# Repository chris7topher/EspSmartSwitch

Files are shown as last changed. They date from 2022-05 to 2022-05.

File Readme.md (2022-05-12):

# DIY ESP8266 SmartSwitch

## Folder structure
### 3D-Parts
Here you can find the 3D models for the 3D printed parts

### Arduino
If you want to use your own code with MQTT instead of Tasmota you can find an example for Arduino here

### PCB
Here you find the schematic, the Gerber data and the PCB design

### Tasmota
Here you can find the tasmota configuration and a ready built tasmota firmware for the SmartSwitch

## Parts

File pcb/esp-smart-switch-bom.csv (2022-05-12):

ID | Name | Designator | Footprint | Quantity | Manufacturer Part | Manufacturer | Supplier | Supplier Part | Price | Pins | 3DModel | Assembly Type | LCSC Assembly | Paste Type | Contributor | Package Display | SMT Type | description | link
1 | R120 | R1 | R0603 | 1 | RNCS0603BTC10R0 | SEI(Stackpole Electronics Inc.) | LCSC | C2523745 | 0.093 | 2 | R0603_L1.6-W0.8-H0.8 |  |  |  | LCSC |  |  |  | https://item.szlcsc.com/137208.html
2 | RGB LED | LED | LED_WP154A4SEJ3VBDZGC/CA_KNB | 1 | WP154A4SEJ3VBDZGC/CA | Kingbright | Mouser | 604-WP154A43VBDZGCCA |  | 4 | LED-TH-5mm_B |  |  |  | Chamberland | No |  |  | https://www.mouser.com/ProductDetail/Kingbright/WP154A4SEJ3VBDZGC-CA
3 | SKHHCRA010 | SW1,SW2,SW3,SW4 | SW-TH_4P-L6.0-W6.0-P4.50-LS6.5 | 4 | SKHHCRA010 | ALPS Electric | LCSC | C139810 | 0.226 | 4 | SW-TH_4P-L6.0-W6.0-H5.0-LS6.5-P4.50 | manualWeld | Yes | expand | LCSC |  | Extend |  | https://item.szlcsc.com/14483.html
4 | TTP223E-BA6 | U1 | SOT-23-6_6PIN-L3.00-W3.00-PITCH0.95-BL | 1 | TTP223E-BA6 | TONTEK | LCSC | C129457 |  | 6 |  |  |  |  |  |  |  |  | https://so.szlcsc.com/global.html?c=&k=C370887
5 | 1uF | C1 | C0805 | 1 | 0805F105M500 | Huaxin S&T | LCSC | C152857 | 0.021 | 2 | C0805_L2.0-W1.3-H1.3 |  |  |  | LCSC |  |  |  | https://item.szlcsc.com/373011.html
6 | 30pF | C2 | C0805 | 1 | 0805F105M500 | Huaxin S&T | LCSC | C152857 | 0.021 | 2 | C0805_L2.0-W1.3-H1.3 |  |  |  | LCSC |  |  |  | https://item.szlcsc.com/373011.html
7 | Header-Male-2.54_1x1 | TOUCH | HDR-TH_1P-P2.54-V-M | 1 | Header-Male-2.54_1x1 | ReliaPro | LCSC | C81276 | 0.007 | 1 | HDR2.54-M-LI-1X1P | manualWeld | Yes | expand | 立创EDA官方封装库 |  | Extend |  | https://item.szlcsc.com/82426.html
8 | 220S-1*4P H=8.5MM Ytype Gold-plated | TEMP | HDR-TH_4P-P2.54-V | 1 | 220S-1*4P H=8.5MM Ytype Gold-plated | Ckmtw | LCSC | C124413 | 0.1 | 4 | HDR-M-2.54_1x4 | manualWeld | Yes | expand | LCSC |  | Extend |  | https://lcsc.com/product-detail/Pin-Header-Female-Header_Made-in-China-Made-in-China-Headers-Pins1-4-pitch2-54mm_C59481.html
9 | ESP-12F(ESP8266MOD) | U2 | WIFIM-SMD_ESP-12F-ESP8266MOD | 1 | ESP-12F(ESP8266MOD) | Ai-Thinker | LCSC | C82891 | 1.731 | 22 | WIFIM-SMD_WIFI-L24.0-W16.0-H3.1 | smtWeld |  | recommend | 立创EDA官方封装库 |  |  |  | https://item.szlcsc.com/84052.html
10 | B | DC_IN | C0402 | 1 |  |  |  |  |  | 2 |  |  |  |  | SparkFun
11 | HLK-PM03 | U6 | TORBEN-PSU | 1 | HLK-PM03 |  |  |  |  | 4 | PWRM-TH_HLK-PM03 |  |  |  | t_andersen
12 | KF350-3.5-2P | U5,U4 | CONN-TH_P3.50_KF350-3.5-2P | 2 | KF350-3.5-2P | Cixi Kefa Elec | LCSC | C474892 | 0.094 | 2 | CONN-TH_P3.50_KF350-3.5-2P | manualWeld | Yes | expand | LCSC |  | Extend |  | https://item.szlcsc.com/481510.html
13 | HT7333-A_C73726 | U7 | TO-92-3_L5.1-W4.1-P1.27-L | 1 | HT7333-A | Holtek Semicon | LCSC | C73726 | 0.173 | 3 | TO-92-3_L4.9-W3.7-P1.27-L |  |  |  | LCSC |  |  |  | https://item.szlcsc.com/39513.html

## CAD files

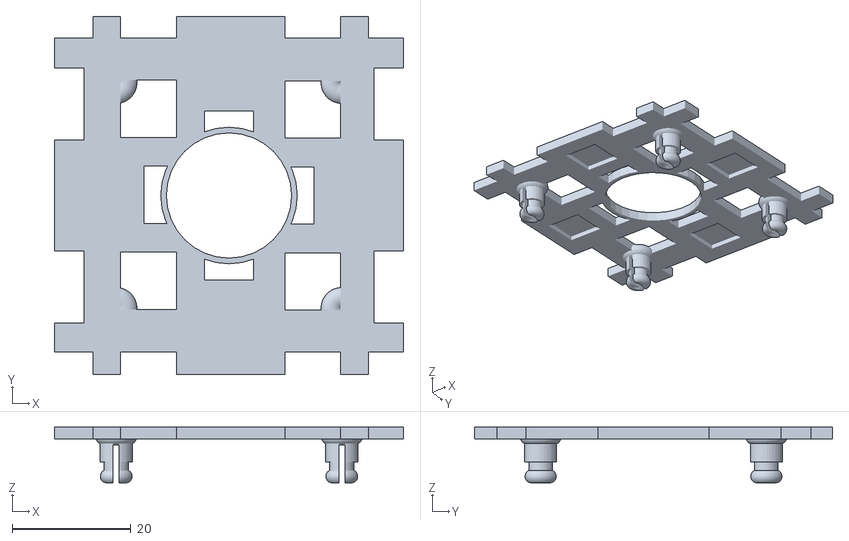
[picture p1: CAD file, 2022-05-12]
3d-parts/glass-holder.stl
58.8 x 60.3 x 9.37

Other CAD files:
3d-parts/glass-holder.blend

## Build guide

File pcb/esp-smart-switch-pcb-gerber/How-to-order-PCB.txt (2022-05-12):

How to Order PCB

Please refer to:
https://docs.easyeda.com/en/PCB/Order-PCB

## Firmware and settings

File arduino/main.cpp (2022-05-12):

#include <Arduino.h>
#include <ESP8266WiFi.h>
#include <ESP8266HTTPClient.h>
#define GET_CHIPID() (ESP.getChipId())

#include <FS.h>
#include <ArduinoOTA.h>
#include <PubSubClient.h>
#include <AutoConnect.h>
#include <SmartButton.h>

#include <AHT10.h>
#include <Wire.h>

uint8_t readStatus = 0;

AHT10 myAHT10(AHT10_ADDRESS_0X38);

#define RGB_RED (1)   // R
#define RGB_GREEN (3) // G
#define RGB_BLUE (0)  // B
int ledState_red = 0;
int ledState_green = 0;
int ledState_blue = 0;

#define BTN_L (13)
#define BTN_T (16)
#define BTN_R (14)
#define BTN_B (12)
#define BTN_C (2)

SmartButton buttons[] = {
  SmartButton("button-left", BTN_L),
  SmartButton("button-top", BTN_T),
  SmartButton("button-center", BTN_C),
  SmartButton("button-right", BTN_R),
  SmartButton("button-bottom", BTN_B)
};

const int SHORT_PRESS_TIME = 500; // 500 milliseconds

#define PARAM_FILE "/param.json"
#define AUX_SETTING_URI "/mqtt_setting"
#define AUX_SAVE_URI "/mqtt_save"
#define AUX_TEST_URI "/test"

typedef ESP8266WebServer WiFiWebServer;
AutoConnect portal;
AutoConnectConfig config;
WiFiClient wifiClient;
PubSubClient mqttClient(wifiClient);

//Definition of functions:
void callback(String topic, byte *message, int length);
void redirect(String uri);
void handleButton(SmartButton *button, byte normalState, int shortPressTime);

//MQTT Settings
String mqttServer = "192.168.178.99";
String mqttPort = "1884";
String mqttUser = "admin";
String mqttPW = "admin";
String mqttDeviceName = "SmartLightSwitch-" + String(GET_CHIPID(), HEX);

// Declare AutoConnectElements for the page asf /mqtt_setting
ACStyle(style, "label+input,label+select{position:sticky;left:120px;width:230px!important;box-sizing:border-box;}");
ACText(header, "<h2>MQTT Settings</h2>", "text-align:center;color:#2f4f4f;padding:10px;");
ACInput(inMqttserver, mqttServer.c_str(), "MQTT-Server", "", "e.g. 192.168.172.99");
ACInput(inMqttport, mqttPort.c_str(), "MQTT Port", "", "e.g. 1883 or 1884");
ACInput(inMqttuser, mqttUser.c_str(), "MQTT User", "", "default: admin");
ACInput(inMqttpw, mqttPW.c_str(), "MQTT Password", "", "default: admin");
ACInput(inMqttDeviceName, mqttDeviceName.c_str(), "MQTT Device Name", "", (String("default: ") + mqttDeviceName).c_str());
ACText(mqttState, "MQTT-State: none", "");
ACSubmit(save, "Save", AUX_SAVE_URI);
ACSubmit(discard, "Discard", "/");
ACElement(newline, "<hr>");
// Declare the custom Web page as /mqtt_setting and contains the AutoConnectElements
AutoConnectAux mqtt_setting(AUX_SETTING_URI, "MQTT Settings", true, {style, header, newline, inMqttserver, inMqttport, newline, inMqttuser, inMqttpw, inMqttDeviceName, newline, mqttState, newline, save, discard});

// Declare AutoConnectElements for the page as /mqtt_save
ACText(caption2, "<h4>Parameters available as:</h4>", "text-align:center;color:#2f4f4f;padding:10px;");
ACText(parameters);
ACSubmit(back2config, "Back", AUX_SETTING_URI);
// Declare the custom Web page as /mqtt_save and contains the AutoConnectElements
AutoConnectAux mqtt_save(AUX_SAVE_URI, "MQTT Settings", false, {caption2, parameters, back2config});

bool mqttConnect()
{
  if (mqttServer.length() <= 0)
  {
    return false;
  }

  mqttClient.setServer(mqttServer.c_str(), atoi(mqttPort.c_str()));
  mqttClient.setCallback(callback);

  if (mqttClient.connect(mqttDeviceName.c_str(), mqttUser.c_str(), mqttPW.c_str()))
  {
    mqttClient.publish((mqttDeviceName + "/ip").c_str(), WiFi.localIP().toString().c_str());
    mqttClient.subscribe((mqttDeviceName + "/led-red").c_str());
    mqttClient.subscribe((mqttDeviceName + "/led-green").c_str());
    mqttClient.subscribe((mqttDeviceName + "/led-blue").c_str());
    mqttState.value = "MQTT-State: <b style=\"color: green;\">Connected</b>";
    return true;
  }
  else
  {
    mqttState.value = "MQTT-State: <b style=\"color: red;\">Disconnected</b>";
  }
  return false;
}

// This functions is executed when some device publishes a message to a topic that your ESP8266 is subscribed to
// Change the function below to add logic to your program, so when a device publishes a message to a topic that
// your ESP8266 is subscribed you can actually do something
void callback(String topic, byte *message, int length)
{

  String messageTemp;
  for (int i = 0; i < length; i++)
  {
    messageTemp += (char)message[i];
  }
  messageTemp += '\n';

  if (topic == (mqttDeviceName + "/led-red").c_str())
  {
    ledState_red = messageTemp.toInt();
  }
  else if (topic == (mqttDeviceName + "/led-green").c_str())
  {
    ledState_green = messageTemp.toInt();
  }
  else if (topic == (mqttDeviceName + "/led-blue").c_str())
  {
    ledState_blue = messageTemp.toInt();
  }
}

String loadParams()
{
  File param = SPIFFS.open(PARAM_FILE, "r");
  if (param)
  {
    if (mqtt_setting.loadElement(param))
    {
      mqttServer = mqtt_setting["inMqttserver"].value;
      mqttServer.trim();
      mqttPort = mqtt_setting["inMqttport"].value;
      mqttPort.trim();
      mqttUser = mqtt_setting["inMqttuser"].value;
      mqttUser.trim();
      mqttPW = mqtt_setting["inMqttpw"].value;
      mqttPW.trim();
      mqttDeviceName = mqtt_setting["inMqttDeviceName"].value;
      mqttDeviceName.trim();
    }
    param.close();
  }
  return String("");
}

// Retreive the value of each element entered by '/mqtt_setting'.
String saveParams(AutoConnectAux &aux, PageArgument &args)
{
  mqttServer = inMqttserver.value;
  mqttServer.trim();

  mqttPort = inMqttport.value;
  mqttPort.trim();

  mqttUser = inMqttuser.value;
  mqttUser.trim();

  mqttPW = inMqttpw.value;
  mqttPW.trim();

  mqttDeviceName = inMqttDeviceName.value;
  mqttDeviceName.trim();

  // The entered value is owned by AutoConnectAux of /mqtt_setting.
  // To retrieve the elements of /mqtt_setting, it is necessary to get
  // the AutoConnectAux object of /mqtt_setting.
  File param = SPIFFS.open(PARAM_FILE, "w");
  mqtt_setting.saveElement(param, {"inMqttserver", "inMqttport", "inMqttuser", "inMqttpw", "inMqttDeviceName"});
  param.close();

  // Echo back saved parameters to AutoConnectAux page.
  String echo = "Server: " + mqttServer + "<br>";
  echo += "Port: " + mqttPort + "<br>";
  echo += "User: " + mqttUser + "<br>";
  echo += "Password: " + mqttPW + "<br>";
  parameters.value = echo;
  mqttClient.disconnect();
  return String("");
}

void handleRoot()
{
  redirect("/_ac");
}

void redirect(String uri)
{
  WiFiWebServer &webServer = portal.host();
  webServer.sendHeader("Location", String("http://") + webServer.client().localIP().toString() + uri);
  webServer.send(302, "text/plain", "");
  webServer.client().flush();
  webServer.client().stop();
}

void setup()
{
  Wire.begin(SDA, SCL);

  SPIFFS.begin();
  config.title = "MQTT Smart Light Switch";
  config.apid = "esp-smart-light-switch";
  config.autoReconnect = true;
  config.reconnectInterval = 4;   // Seek interval time is 120[s].
  config.psk = "";
  config.autoReset = true;
  config.portalTimeout = 60000; // It will time out in 60 seconds
  config.retainPortal = true;
  portal.config(config);
  loadParams();
  // Join the custom Web pages and register /mqtt_save handler
  portal.join({mqtt_setting, mqtt_save});
  portal.on(AUX_SAVE_URI, saveParams);

  if (portal.begin())
  {
    ArduinoOTA.begin();
  }
  WiFiWebServer &webServer = portal.host();
  webServer.on("/", handleRoot);

  //Handle LEDs
  pinMode(RGB_RED, OUTPUT);
  pinMode(RGB_GREEN, OUTPUT);
  pinMode(RGB_BLUE, OUTPUT);
  analogWrite(RGB_RED, ledState_red);
  analogWrite(RGB_GREEN, ledState_green);
  analogWrite(RGB_BLUE, ledState_blue);

  //Init Buttons
  pinMode(BTN_L, INPUT_PULLUP);
  pinMode(BTN_T, INPUT_PULLDOWN_16);
  pinMode(BTN_C, INPUT_PULLUP);
  pinMode(BTN_R, INPUT_PULLUP);
  pinMode(BTN_B, INPUT_PULLUP);

  myAHT10.begin();
}

void loop()
{
  if (WiFi.status() == WL_CONNECTED)
  {
    //The following things can only be handled if wifi is connected
    ArduinoOTA.handle();
    if (!mqttClient.connected())
    {
      mqttConnect();
    }
    else
    {
      mqttClient.loop();
    }
  }

  // set the LED with the ledState of the variable:
  analogWrite(RGB_RED, ledState_red);
  analogWrite(RGB_GREEN, ledState_green);
  analogWrite(RGB_BLUE, ledState_blue);

  //BTN
  handleButton(&buttons[0], HIGH, SHORT_PRESS_TIME);
  handleButton(&buttons[1], LOW, SHORT_PRESS_TIME);
  handleButton(&buttons[2], HIGH, SHORT_PRESS_TIME * 2);
  handleButton(&buttons[3], HIGH, SHORT_PRESS_TIME);
  handleButton(&buttons[4], HIGH, SHORT_PRESS_TIME);

  //*Temperature
  if(millis() % 5000 == 0){
    mqttClient.publish((mqttDeviceName + "/temperature").c_str(), String(myAHT10.readTemperature()).c_str());
    mqttClient.publish((mqttDeviceName + "/humidity").c_str(), String(myAHT10.readHumidity()).c_str());
  }
  portal.handleClient();
}

void handleButton(SmartButton *btn, byte normalState, int shortPressTime)
{
  int currentState = digitalRead(btn->pin);

  if (btn->lastState == normalState && currentState != normalState)
  { // button is pressed
    btn->pressedTime = millis();
    btn->isPressing = true;
    btn->isLongDetected = false;
  }
  else if (btn->lastState != normalState && currentState == normalState)
  { // button is released
    btn->isPressing = false;
    btn->releasedTime = millis();

    long pressDuration = btn->releasedTime - btn->pressedTime;

    if (pressDuration < shortPressTime && pressDuration > 20)
      mqttClient.publish((mqttDeviceName + "/" + btn->name).c_str(), "S");
  }

  if (btn->isPressing == true && btn->isLongDetected == false)
  {
    long pressDuration = millis() - btn->pressedTime;

    if (pressDuration > shortPressTime)
    {
      mqttClient.publish((mqttDeviceName + "/" + btn->name).c_str(), "L");
      btn->isLongDetected = true;
    }
  }
  // save the the last state
  btn->lastState = currentState;
}

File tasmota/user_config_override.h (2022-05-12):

/*
  user_config_override.h - user configuration overrides my_user_config.h for Tasmota

  Copyright (C) 2021  Theo Arends

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
  You should have received a copy of the GNU General Public License
  along with this program.  If not, see <http://www.gnu.org/licenses/>.
*/

#ifndef _USER_CONFIG_OVERRIDE_H_
#define _USER_CONFIG_OVERRIDE_H_

/*****************************************************************************************************\
 * USAGE:
 *   To modify the stock configuration without changing the my_user_config.h file:
 *   (1) copy this file to "user_config_override.h" (It will be ignored by Git)
 *   (2) define your own settings below
 *
 ******************************************************************************************************
 * ATTENTION:
 *   - Changes to SECTION1 PARAMETER defines will only override flash settings if you change define CFG_HOLDER.
 *   - Expect compiler warnings when no ifdef/undef/endif sequence is used.
 *   - You still need to update my_user_config.h for major define USE_MQTT_TLS.
 *   - All parameters can be persistent changed online using commands via MQTT, WebConsole or Serial.
\*****************************************************************************************************/

/*
Examples :

// -- Master parameter control --------------------
#undef  CFG_HOLDER
#define CFG_HOLDER        4617                   // [Reset 1] Change this value to load SECTION1 configuration parameters to flash

// -- Setup your own Wifi settings  ---------------
#undef  STA_SSID1
#define STA_SSID1         "YourSSID"             // [Ssid1] Wifi SSID

#undef  STA_PASS1
#define STA_PASS1         "YourWifiPassword"     // [Password1] Wifi password
*/
// -- Setup your own MQTT settings  ---------------
#undef  MQTT_HOST
#define MQTT_HOST         "192.168.178.99" // [MqttHost]

#undef  MQTT_PORT
#define MQTT_PORT         1883                   // [MqttPort] MQTT port (10123 on CloudMQTT)

#undef  MQTT_USER
#define MQTT_USER         "enter_your_your_user_here"         // [MqttUser] Optional user

#undef  MQTT_PASS
#define MQTT_PASS         "enter_your_password_here"         // [MqttPassword] Optional password

/*
// You might even pass some parameters from the command line ----------------------------
// Ie:  export PLATFORMIO_BUILD_FLAGS='-DUSE_CONFIG_OVERRIDE -DMY_IP="192.168.1.99" -DMY_GW="192.168.1.1" -DMY_DNS="192.168.1.1"'

#ifdef MY_IP
#undef  WIFI_IP_ADDRESS
#define WIFI_IP_ADDRESS     MY_IP                // Set to 0.0.0.0 for using DHCP or enter a static IP address
#endif

#ifdef MY_GW
#undef  WIFI_GATEWAY
#define WIFI_GATEWAY        MY_GW                // if not using DHCP set Gateway IP address
#endif

#ifdef MY_DNS
#undef  WIFI_DNS
#define WIFI_DNS            MY_DNS               // If not using DHCP set DNS IP address (might be equal to WIFI_GATEWAY)
#endif

#ifdef MY_DNS2
#undef  WIFI_DNS2
#define WIFI_DNS2           MY_DNS2              // If not using DHCP set DNS IP address (might be equal to WIFI_GATEWAY)
#endif

// !!! Remember that your changes GOES AT THE BOTTOM OF THIS FILE right before the last #endif !!!
*/

// Passwords
#undef STA_SSID1
#define STA_SSID1      "YOUR_SSID"

#undef STA_PASS1
#define STA_PASS1      "YOUR_WIFI_PASSWORD"


// Temperatur Sensor
#define USE_AHT1x

// Template
#define USER_TEMPLATE "{\"NAME\":\"SmartSwitch\",\"GPIO\":[418,416,36,417,640,608,1,1,34,35,33,1,96,1],\"FLAG\":0,\"BASE\":18}"

#define USE_WEBSEND_RESPONSE

//HAAS
#undef HOME_ASSISTANT_DISCOVERY_ENABLE
#define HOME_ASSISTANT_DISCOVERY_ENABLE   false

// Use only singe press for fast response, if hold is needed this must be set to false (setoption13)
#undef KEY_ONLY_SINGLE_PRESS  false
#define KEY_ONLY_SINGLE_PRESS   true

#undef FALLBACK_MODULE
#define FALLBACK_MODULE        USER_MODULE

#undef FRIENDLY_NAME
#define FRIENDLY_NAME          "SmartSwitch" 

#undef KEY_HOLD_TIME
#define KEY_HOLD_TIME 10

#undef MQTT_BUTTON_TOPIC
#define MQTT_BUTTON_TOPIC      "1"  

#undef MQTT_CLIENT_ID
#define MQTT_CLIENT_ID "SmartSwitch_%06X"

// Try to disable firmware reset
#undef KEY_DISABLE_MULTIPRESS
#define KEY_DISABLE_MULTIPRESS true

// Disable other temp sensors
#ifdef USE_ADE7953
#undef USE_ADE7953                              
#endif 

#undef MQTT_BUTTONS                              
#define MQTT_BUTTONS true

#ifdef MQTT_SWITCHES
#undef MQTT_SWITCHES                              
#define MQTT_SWITCHES true
#endif 

#ifdef USE_VEML6075
#undef USE_VEML6075                              
#endif 

#undef NTP_SERVER1    
#define NTP_SERVER1 "192.168.178.99"                          

#undef NTP_SERVER2      
#define NTP_SERVER2 ""                        

#undef NTP_SERVER3      
#define NTP_SERVER3 ""                        

#ifdef USE_DOMOTICZ
#undef USE_DOMOTICZ                              
#endif 

#ifdef USE_HOME_ASSISTANT
#undef USE_HOME_ASSISTANT                              
#endif 

#endif  // _USER_CONFIG_OVERRIDE_H_

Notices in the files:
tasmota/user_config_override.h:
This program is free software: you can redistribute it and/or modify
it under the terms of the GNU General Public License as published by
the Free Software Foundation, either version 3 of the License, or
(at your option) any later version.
